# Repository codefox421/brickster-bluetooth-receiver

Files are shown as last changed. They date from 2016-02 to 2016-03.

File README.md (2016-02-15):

# BricksTer &ndash; Bluetooth Receiver

BricksTer Bluetooth Receiver top side&nbsp;&nbsp;&nbsp;BricksTer Bluetooth Receiver bottom side

The BricksTer Bluetooth Receiver lets you wirelessly control your LEGO creations from a smart phone, tablet, or PC. It is compatible with the NXT programmable brick. This repository houses the Eagle CAD schematic and design files for the printed circuit board along with the firmware for the receiver.

## Getting Started

### Part List

Components can be ordered from any distributor (e.g. DigiKey, Mouser, etc).
[Please see the Bill of Materials for the list of components.](https://github.com/BTbricks/brickster-bluetooth-receiver/blob/master/8884bt%20Remote%20Control%20Receiver/board/BOM.md)

The rev. 2 board can be purchased from OSH Park.
[Click here to view the OSH Park project page.](https://oshpark.com/shared_projects/jNrizzs2)

### Programming the Board

Once your board is soldered, use the Arduino IDE to load the firmware onto the microcontroller.
The IDE is available for free and can be downloaded from http://arduino.cc/main/software

#### Setting up the Arduino Environment

The microcontroller is an ATtiny84, which is not regularly supported by the Arduino IDE.
[Please visit the Arduino support page to learn more about using Arduino with the ATtiny84.](http://playground.arduino.cc/Main/ArduinoOnOtherAtmelChips)

Download the [Attiny 44/45/84/85 files](https://github.com/damellis/attiny/archive/master.zip) and extract them to `{ARDUINO}/hardware/`, where `{ARDUINO}` represents the directory into which the Arduino IDE and supporting files have been installed. Once completed, your directory should look like this:

```
{ARDUINO}
└-hardware
  └-attiny
    ├-boards.txt
    └-variants
      ├-tiny8
      | └-pins_arduino.h
      └-tiny14
        └-pins_arduino.h
```

#### Burning the "Bootloader"

The ATtiny84 comes from the factory running on an internal 1 MHz clock. In order to run the BricksTer firmware, the ATtiny84 must be told to use its interal 8 MHz clock.

* Connect your board to your computer via the programmer
* Apply power to the power-in Power Functions wire
* Open the Arduino IDE
* Ensure you have selected the proper serial port (`Tools > Serial Port`) and can communicate with the microcontroller
* Select `Tools > Board > ATtiny84 (internal 8 Mhz clock)`
* Select `Tools > Burn Bootloader`
* Wait for the programmer to finish, the IDE should display a success message

#### Loading the Firmware

* Connect your board to your computer via the programmer
* Apply power to the power-in Power Functions wire
* Open the Arduino IDE
* Ensure you have selected the proper serial port (`Tools > Serial Port`) and can communicate with the microcontroller
* Select `Tools > Board > ATtiny84 (internal 8 Mhz clock)`
* Open the firmware file, [`brickster8884bt.ino`](https://github.com/BTbricks/brickster-bluetooth-receiver/blob/master/8884bt%20Remote%20Control%20Receiver/firmware/brickster8884bt.ino)
* Click the Upload button on the Arduino IDE (circle with a right-pointing arrow)
* Wait for the the IDE and programmer to finish, the IDE should display a success message

Note: Use of a Atmel AVRISPmk2 programmer is strongly advised. Other programmers have been known to work, but we can only provide support for the AVRISPmk2.

### File Formats

Design files are created in CadSoft Eagle PCB Design Software.
A free version of the software can be downloaded from www.cadsoftusa.com

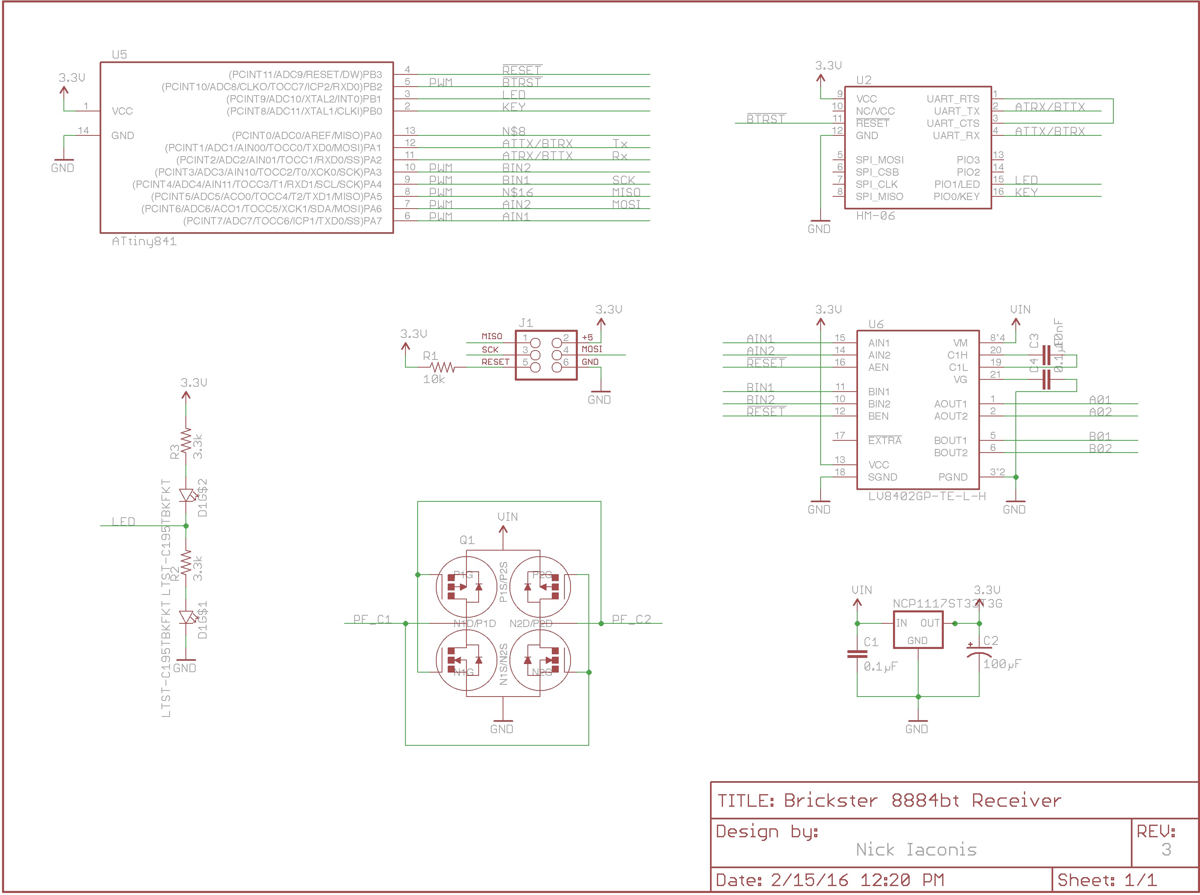
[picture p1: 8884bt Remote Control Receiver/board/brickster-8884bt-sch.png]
BricksTer Bluetooth Receiver schematic
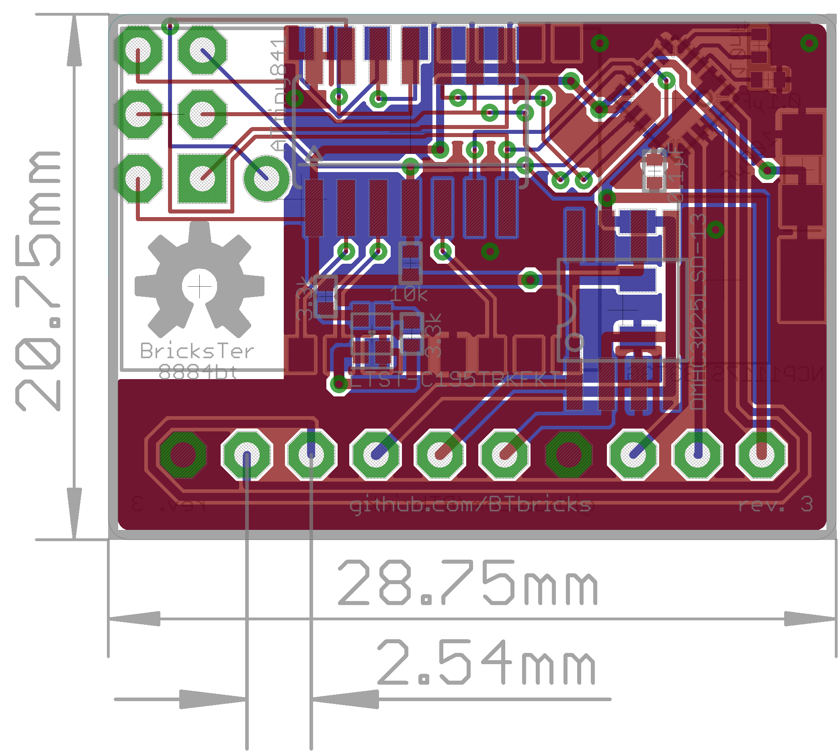
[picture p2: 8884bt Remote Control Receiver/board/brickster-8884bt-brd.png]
BricksTer Bluetooth Receiver board design
&nbsp;&nbsp;&nbsp;

## Ordering the PCB

You can order the unpopulated printed circuit board from OSH Park by following the link below.



## Distribution License

Where possible, this project uses the MIT license. [Please see the license file for full details.](https://github.com/BTbricks/brickster-bluetooth-receiver/blob/master/LICENSE)

## Contributing

The project is open to all issues and pull requests.
If you have any other questions or feedback, please [contact the project maintainers](https://github.com/orgs/BTbricks/members).

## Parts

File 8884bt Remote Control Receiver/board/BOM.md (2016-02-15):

# Bill of Materials

Listed here is a complete bill of materials for assembling one bluetooth receiver.

## Example listing

+ **Identifier** Device Package (ManufacturerPartNumber) _comment_

## 8884bt Bluetooth Receiver

+ **U1** ATtiny841 SOIC14 (ATTINY841-SSU)
+ **U2** MotorDriver 24-WFQFN (LV8402GP-TE-L-H)
+ **U3** Regulator3.3V SOT223 (NCP1117ST33T3G)
+ **U4** BluetoothModule SMD16 (HM-13)

+ **Q1** MOSFET2N+2P SOIC8 (DMHC3025LSD-13)

+ **D1** Blue/OrangeLED 0605 (LTST-C195TBKFKT)

+ **C1/C4** CapCer0.1µF 0402 (GRM155R71C104KA88D) _or similar_
+ **C2** CapCer100µF 1206 (GRM31CE70G107ME39L) _or similar_
+ **C3** CapCer10nF 0402 (GRM155R71C103KA01D) _or similar_

+ **R1** Res10kOhm 0402 (RR0510P-103-D) _or similar_
+ **R2/R3** Res3.3kOhm 0402 (RR0510P-332-D) _or similar_

+ **J1** ProgrammerICSP N/A (N/A) _used to program the ATtiny841, use of pogo pins is advised, no external power!_

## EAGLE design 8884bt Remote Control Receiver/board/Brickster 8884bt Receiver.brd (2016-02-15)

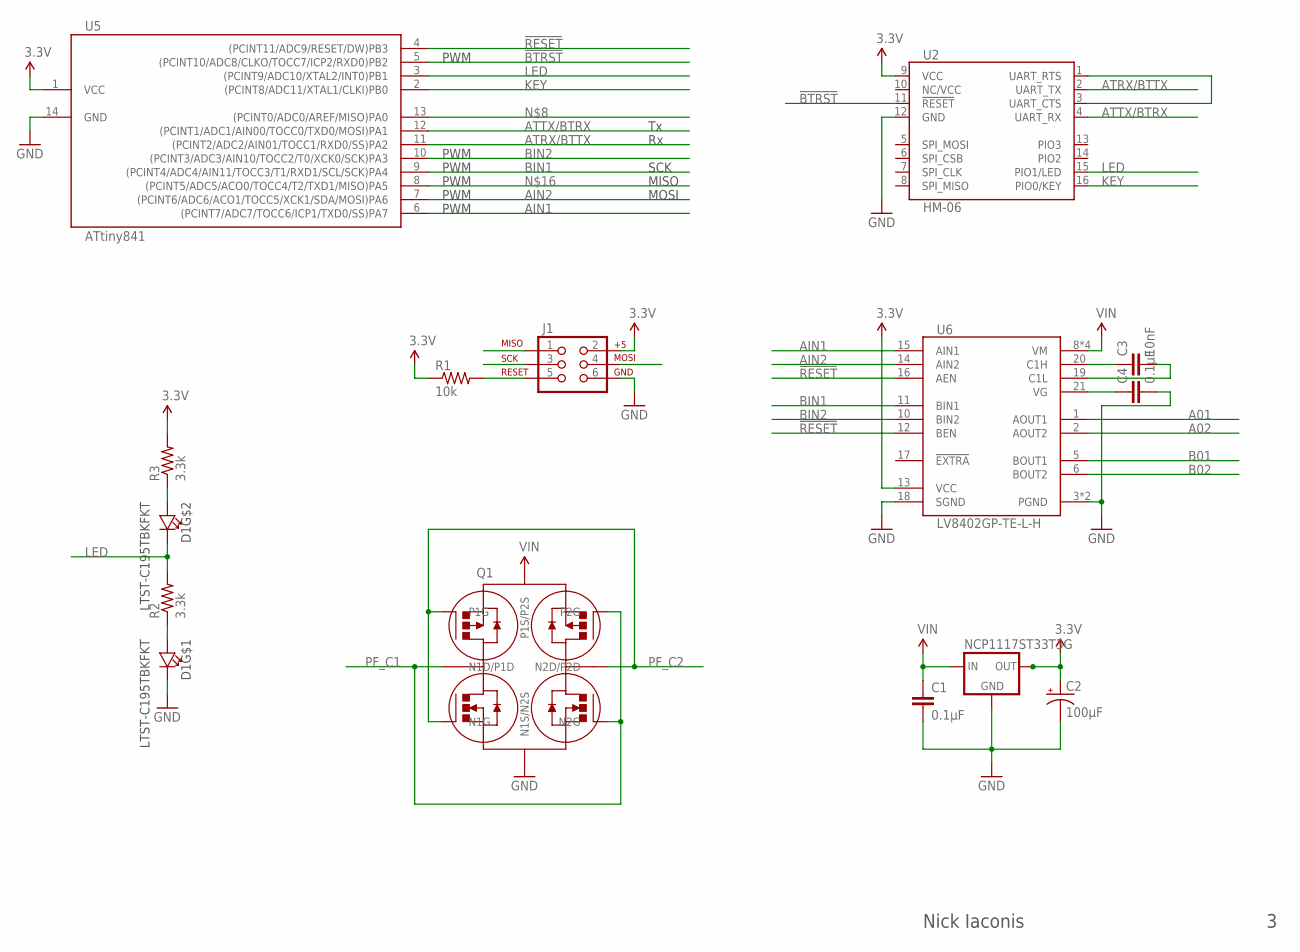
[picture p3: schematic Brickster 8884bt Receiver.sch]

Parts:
C1, C4: 0.1µF; 0402
C2: 100µF; 1206
C3: 10nF; 0402
D1: LTST-C195TBKFKT; CHIP-LTST
J1: AVR_SPI_PRG_6NS; 2X3-NS
NCP1117ST33T3G: IC_RT9164A; SOT223
Q1: DMHC3025LSD-13; SO8
R1: 10k; 0402; PARTNO ERJ-3GEYJ103V
R2, R3: 3.3k; 0402; PARTNO ERJ-3GEYJ103V
U2: HM-06; HM-05/06/07
U5: ATtiny841; 14SOICN
U6: LV8402GP-TE-L-H; VCT24

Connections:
3.3V: C2.1 (+), J1.2, NCP1117ST33T3G.2 (OUT), NCP1117ST33T3G.4, R1.1, R3.2, U2.9 (VCC), U5.1 (VCC), U6.13 (VCC)
!BTRST: U2.11 (!RESET), U5.5 ((PCINT10/ADC8/CLKO/TOCC7/ICP2/RXD0)PB2)
!RESET: J1.5, R1.2, U5.4 ((PCINT11/ADC9/RESET/DW)PB3), U6.12 (BEN), U6.16 (AEN)
A01: U6.1 (AOUT1)
A02: U6.2 (AOUT2)
AIN1: U5.6 ((PCINT7/ADC7/TOCC6/ICP1/TXD0/SS)PA7), U6.15 (AIN1)
AIN2: J1.4, U5.7 ((PCINT6/ADC6/ACO1/TOCC5/XCK1/SDA/MOSI)P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), U6.14 (AIN2)
ATRX/BTTX: U2.2 (UART_TX), U5.11 ((PCINT2/ADC2/AIN01/TOCC1/RXD0/SS)PA2)
ATTX/BTRX: U2.4 (UART_RX), U5.12 ((PCINT1/ADC1/AIN00/TOCC0/TXD0/MOSI)PA1)
B01: U6.5 (BOUT1)
B02: U6.6 (BOUT2)
BIN1: J1.3, U5.9 ((PCINT4/ADC4/AIN11/TOCC3/T1/RXD1/SCL/SC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), U6.11 (BIN1)
BIN2: U5.10 ((PCINT3/ADC3/AIN10/TOCC2/T0/XCK0/SCK)PA3), U6.10 (BIN2)
GND: C1.2, C2.2 (-), C4.2, D1.3, J1.6, NCP1117ST33T3G.1 (GND), Q1.P$3 (N1S/N2S), U2.12 (GND), U5.14 (GND), U6.3 (PGND), U6.4 (PGND), U6.18 (SGND)
KEY: U2.16 (PIO0/KEY), U5.2 ((PCINT8/ADC11/XTAL1/CLKI)PB0)
LED: D1.4, R2.2, U2.15 (PIO1/LED), U5.3 ((PCINT9/ADC10/XTAL2/INT0)PB1)
unnamed: D1.2, R3.1
unnamed: D1.1, R2.1
unnamed: U2.1 (UART_RTS), U2.3 (UART_CTS)
unnamed: C3.2, U6.19 (C1L)
unnamed: C4.1, U6.21 (VG)
unnamed: C3.1, U6.20 (C1H)
unnamed: J1.1, U5.8 ((PCINT5/ADC5/ACO0/TOCC4/T2/TXD1/MISO)PA5)
PF_C1: Q1.P$2 (N1D/P1D), Q1.P$4 (N2G), Q1.P$5 (P2G)
PF_C2: Q1.P$1 (N1G), Q1.P$6 (N2D/P2D), Q1.P$8 (P1G)
VIN: C1.1, NCP1117ST33T3G.3 (IN), Q1.P$7 (P1S/P2S), U6.8 (VM), U6.9 (VM), U6.22 (VM), U6.23 (VM)

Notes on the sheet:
Nick Iaconis
PWM
SCK
MISO
MOSI

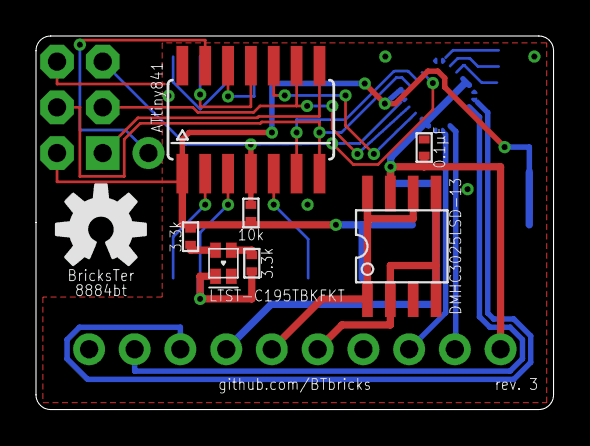
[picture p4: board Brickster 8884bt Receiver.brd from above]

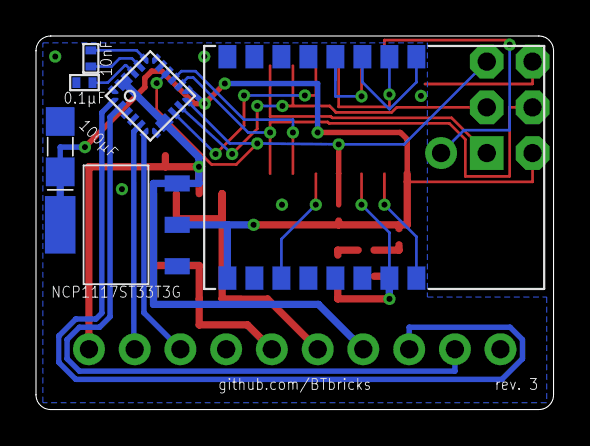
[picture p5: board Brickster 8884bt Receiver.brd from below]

Board: 2 copper layers, 28.8 x 20.8 mm, 15 parts (6 on the bottom side), 22 nets.

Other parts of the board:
LOGO1: OSHW-LOGOM; OSHW-LOGO-M

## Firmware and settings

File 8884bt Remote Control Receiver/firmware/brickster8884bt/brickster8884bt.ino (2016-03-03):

/*------------------------------------------------------------------------------
  The MIT License (MIT)

  Copyright (c) 2013 Nick Iaconis et al.
  
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
  THE SYSTEM IS PROVIDED "AS IS", WITHOUT WARRANTY OF ANY KIND, EXPRESS OR
  IMPLIED, INCLUDING BUT NOT LIMITED TO THE WARRANTIES OF MERCHANTABILITY,
  FITNESS FOR A PARTICULAR PURPOSE AND NONINFRINGEMENT. IN NO EVENT SHALL THE
  AUTHORS OR COPYRIGHT HOLDERS BE LIABLE FOR ANY CLAIM, DAMAGES OR OTHER
  LIABILITY, WHETHER IN AN ACTION OF CONTRACT, TORT OR OTHERWISE, ARISING FROM,
  OUT OF OR IN CONNECTION WITH THE SYSTEM OR THE USE OR OTHER DEALINGS IN THE
  SYSTEM.
------------------------------------------------------------------------------*/

/*-------------------
  #### ATtiny841 ####
  -------------------
         ____
  VCC  <|*   |> GND
  IO 0 <|    |> IO10
  IO 1 <|    |> IO 9
  RST  <|    |> IO 8
  IO 2 <|    |> IO 7
  IO 3 <|    |> IO 6
  IO 4 <|____|> IO 5

  -------------------*/





/*------------------------------------------------------------------------------

  Override core timers

------------------------------------------------------------------------------*/


const uint8_t PROGMEM digital_pin_to_timer_PGM[] =
{
  NOT_ON_TIMER,
  NOT_ON_TIMER,
  TIMER0A, /* TOCC7 - this is the LED function so let's give it the least desirable timer */
  TIMER2B, /* TOCC6 - this is the AUX function so let's arbitrarily give it TIMER2 */
  TIMER2A, /* TOCC5 - this is the AUX function so let's arbitrarily give it TIMER2 */
  TIMER0B, /* TOCC4 - this is the LED function so let's give it the least desirable timer */
  TIMER1A, /* TOCC3 - this is the MOTOR function so let's arbitrarily give it TIMER1 */
  TIMER1B, /* TOCC2 - this is the MOTOR function so let's arbitrarily give it TIMER1 */
  NOT_ON_TIMER, //This could have pwm, but it's serial 0, and we only get PWM on 6 of the 8 pins at once.
  NOT_ON_TIMER, //see above.
  NOT_ON_TIMER,
  NOT_ON_TIMER,
};

// ATtiny841 Datasheet Table 12-7, TOCCn pins can be assigned various OCnX.
#define CORE_OC0A_PIN  PIN_B2 // TOCC7
#define CORE_OC0B_PIN  PIN_A5 // TOCC4
#define CORE_OC1A_PIN  PIN_A4 // TOCC3
#define CORE_OC1B_PIN  PIN_A3 // TOCC2
#define CORE_OC2A_PIN  PIN_A6 // TOCC5
#define CORE_OC2B_PIN  PIN_A7 // TOCC6

#define CORE_PWM0_PIN       CORE_OC0A_PIN
#define CORE_PWM0_TIMER     0
#define CORE_PWM0_CHANNEL   A

#define CORE_PWM1_PIN       CORE_OC0B_PIN
#define CORE_PWM1_TIMER     0
#define CORE_PWM1_CHANNEL   B

#define CORE_PWM2_PIN       CORE_OC1A_PIN
#define CORE_PWM2_TIMER     1
#define CORE_PWM2_CHANNEL   A

#define CORE_PWM3_PIN       CORE_OC1B_PIN
#define CORE_PWM3_TIMER     1
#define CORE_PWM3_CHANNEL   B

#define CORE_PWM4_PIN       CORE_OC2A_PIN
#define CORE_PWM4_TIMER     2
#define CORE_PWM4_CHANNEL   A

#define CORE_PWM5_PIN       CORE_OC2B_PIN
#define CORE_PWM5_TIMER     2
#define CORE_PWM5_CHANNEL   B



/*------------------------------------------------------------------------------

  Definitions

------------------------------------------------------------------------------*/


// Motor control A
#define mcPin1A 6
#define mcPin2A 7
#define maxA 28
char levelA = 0;
int pwmA = 0;

// Motor control B
#define mcPin1B 3
#define mcPin2B 4
#define maxB 28
char levelB = 0;
int pwmB = 0;

// Channel A commands
#define maskA 83
#define upA 65    // A up         = A
#define downA 66  // A down       = B
#define brakeA 67 // A brake      = C
#define floatA 80 // A float      = P
#define ffwdA 81  // A full fwd   = Q
#define frevA 82  // A full rev   = R

// Channel B commands
#define maskB 108
#define upB 68    // B up         = D
#define downB 72  // B down       = H
#define brakeB 76 // B brake      = L
#define floatB 96 // B float      = `
#define ffwdB 100 // B full fwd   = d
#define frevB 104 // B full rev   = h

// Combine Channel A command with Channel B command using logical OR

// Hardware serial
#define baudRate 9600

// Miscellanious
#define btResetPin 2
#define btConnPin 1
char incomingByte = 0;
char maskedByte = 0;
int pwmLevels[29] = {0, 41,  49,  57,  64, \
                        73,  81,  89,  97, \
                       105, 113, 120, 128, \
                       136, 144, 152, 160, \
                       168, 175, 184, 192, \
                       200, 208, 215, 223, \
                       231, 239, 247, 255};

// Function definitions
void comboMode(const char,      char*, const char, const char, \
               const char, const char, const char, const char, \
               const char, const char, const char, const char);



/*------------------------------------------------------------------------------

  setup

------------------------------------------------------------------------------*/


void setup()
{
  // serial baudrate init
  Serial.begin(baudRate);

  // bluetooth control init
  pinMode(btResetPin, OUTPUT);
  digitalWrite(btResetPin, HIGH); // end Bluetooth reset (enable module)

  // bluetooth connectivity init
  pinMode(btConnPin, INPUT);
  Serial.write("AT+LED1");

  // channel A init
  pinMode(mcPin1A, OUTPUT);
  pinMode(mcPin2A, OUTPUT);
  digitalWrite(mcPin1A, HIGH);
  digitalWrite(mcPin2A, HIGH);

  // channel B init
  pinMode(mcPin1B, OUTPUT);
  pinMode(mcPin2B, OUTPUT);
  digitalWrite(mcPin1B, HIGH);
  digitalWrite(mcPin2B, HIGH);
}



/*------------------------------------------------------------------------------

  loop

------------------------------------------------------------------------------*/


void loop()
{
  // Handle serial communication
  if (Serial.available() > 0)
  {
    // read incoming byte
    incomingByte = Serial.read();


    // Direct PWM mode (fine resolution)
    if (incomingByte & 128) // 1xxx xxxx
    {
      // select proper output: x0xx xxxx -> A / x1xx xxxx -> B
      char* levelX = incomingByte & 64 ? &levelB : &levelA;
      if ((incomingByte & 63) == 0) // xx00 0000 -> float
      {
        // set the level
        *levelX = 0;
        // set the motor control wires
        digitalWrite(incomingByte & 64 ? mcPin1B : mcPin1A, HIGH);
        digitalWrite(incomingByte & 64 ? mcPin2B : mcPin2A, HIGH);
      }
      // xx01 1110, xx01 1111, xx10 0001, xx10 0010  are reserved
      else if ((incomingByte & 63) < 29 || (incomingByte & 63) > 35)
      {
        // set the level (xx1x xxxx are negative and need top 3 bits filled)
        *levelX = (incomingByte & 31) | (incomingByte & 32 ? 224 : 0);
        // motor control wires set at end of input handling for non-stopped levels
      }
      else if ((incomingByte & 63) == 32) // xx10 0000 -> brake
      {
        // set the level
        *levelX = 0;
        // set the motor control wires
        digitalWrite(incomingByte & 64 ? mcPin1B : mcPin1A, LOW);
        digitalWrite(incomingByte & 64 ? mcPin2B : mcPin2A, LOW);
      }
      // notify sender
      Serial.write(*levelX);
    }

    // Combo output mode
    else if (incomingByte & 64) // 01xx xxxx
    {
      // set channel A
      comboMode(incomingByte, &levelA, maxA, maskA, brakeA, floatA, \
                  upA, downA, ffwdA, frevA, mcPin1A, mcPin2A);
      // set channel B
      comboMode(incomingByte, &levelB, maxB, maskB, brakeB, floatB, \
                  upB, downB, ffwdB, frevB, mcPin1B, mcPin2B);
      // notify sender
      maskedByte = abs(levelB >> 2) + (levelB < 0 ? 8 : 0);
      maskedByte = (maskedByte << 4) + abs(levelA >> 2) + (levelA < 0 ? 8 : 0);
      Serial.write(maskedByte);
    }

    // set the pwm
    pwmA = pwmLevels[min(abs(levelA), maxA)];
    pwmB = pwmLevels[min(abs(levelB), maxB)];

    if (pwmA > 0)
    {
      // set the motor control wires (LOW input is HIGH output)
      analogWrite(mcPin1A, (levelA > 0 ? (255 - pwmA) : 255));
      analogWrite(mcPin2A, (levelA < 0 ? (255 - pwmA) : 255));
    }

    if (pwmB > 0)
    {
      // set the motor control wires (LOW input is HIGH output)
      analogWrite(mcPin1B, (levelB > 0 ? (255 - pwmB) : 255));
      analogWrite(mcPin2B, (levelB < 0 ? (255 - pwmB) : 255));
    }
  }
}



/*------------------------------------------------------------------------------

  comboMode handler

------------------------------------------------------------------------------*/



void comboMode(const char incomingByte,      char*  levelX, const char    maxX, \
               const char        maskX, const char  brakeX, const char  floatX, \
               const char          upX, const char   downX, const char   ffwdX, \
               const char        frevX, const char mcPin1X, const char mcPin2X)
{
  maskedByte = incomingByte & maskX;
  // decode command
  if (maskedByte == brakeX || maskedByte == floatX)
  {
    *levelX = 0;
    // set the motor control wires (brake LOW, float HIGH)
    digitalWrite(mcPin1X, (maskedByte == brakeX ? LOW : HIGH));
    digitalWrite(mcPin2X, (maskedByte == brakeX ? LOW : HIGH));
  }
  else
  {
    if (maskedByte == upX)
    {
      if (*levelX >= 0)
      {
        *levelX = min((*levelX + 4) & ~3, maxX);
      }
      else
      {
        if (abs(*levelX) & 3)
          *levelX = -(abs(*levelX) & ~3);
        else
          *levelX += 4;
      }
    }
    else if (maskedByte == downX)
    {
      if (*levelX <= 0)
      {
        *levelX = -min((abs(*levelX) + 4) & ~3, maxX);
      }
      else
      {
        if (*levelX & 3)
          *levelX &= ~3;
        else
          *levelX -= 4;
      }
    }
    else if (maskedByte == ffwdX)
    {
      *levelX = maxX;
    }
    else if (maskedByte == frevX)
    {
      *levelX = -maxX;
    }

    // we have stepped back to float
    if (*levelX == 0)
    {
      digitalWrite(mcPin1X, HIGH);
      digitalWrite(mcPin2X, HIGH);
    }
  }

  // motor control wires set at end of input handling for non-stopped levels
}

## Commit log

2016-02-15 Move ino file into a sketch directory
    This will allow Arduino IDE to open it in place.
2016-02-15 Ensure Bluetooth module is enabled on boot
    Without explicitly writing HIGH to the !BTRST line, the module could be
    in reset mode.
    [brickster8884bt.ino]
2016-02-15 Update receiver to revision 3
    [Brickster 8884bt Receiver.brd, Brickster 8884bt Receiver.sch]

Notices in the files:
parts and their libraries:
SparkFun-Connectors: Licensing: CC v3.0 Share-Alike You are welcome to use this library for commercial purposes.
